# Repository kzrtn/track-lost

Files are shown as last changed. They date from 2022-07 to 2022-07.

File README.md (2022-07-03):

# TRACK LOST
F12 TKL type-C PCB for the Duck Orion. Designed in KiCad 6.0

track lost PCB front
track lost PCB back
track lost PCB traces

## Features
- [QMK](https://docs.qmk.fm/#/) and [VIAL](https://get.vial.today/) compatible
- Uses an RP2040 MCU with 32MB of external flash
- Uses WS2812C-2020 LEDs for smaller footprint and less power usage
- Has more underglow LEDs for better LED diffusion
- Indicators use SK6812mini-e LEDs instead
- Multi-layout
- BOOTRESET button if bootmagic isn't available
- ESD chip to prevent damage from electrostatic discharge
- Polyfuse to prevent overcurrent
- Gerber and files available for manufacturing and assembly with JLCPCB (In `track-lost/JLCPCB folder`)
- Curved traces

## Firmware
WIP

## Multi-Layout Support
- Supports both ANSI and ISO layouts
- Supports both 6.25u and 7u spacebar
- Supports split backspace
- Supports split right shift

Multilayout image

## Indicator LEDs
The typical LEDs on the original Duck Orion PCB are TX LEDs that you have to solder in. But for this PCB, SK6812mini-e reverse-mount ARGB LEDs were used instead.
- Reverse mount to keep all components on the same side of the PCB for cheaper assembly
- RGB and programmable
- NOTE: Because these are surface mounted onto the PCB, they'll likely leak light (I'll update this when I test it out). Could be fixed with light pipes or something else to isolate the rays from each other.

top left indicators
above arrow key indicators

## WIP
- Add photos of PCBs
- Add photos of PCB in case
- Add photo of original PCB LED difussion vs TRACK LOST PCB LED difussion
- Create and add firmware to repo

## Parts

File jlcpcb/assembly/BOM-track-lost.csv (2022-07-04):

Comment | Designator | Footprint | LCSC
D | D1,D10,D11,D12,D13,D14,D15,D16,D17,D18,D19,D2,D20,D21,D22,D23,D24,D25,D26,D27,D28,D29,D3,D30,D31,D32,D33,D34,D35,D36,D37,D38,D39,D4,D40,D41,D42,D43,D44,D45,D46,D47,D48,D49,D5,D50,D51,D52,D53,D54,D55,D56,D57,D58,D59,D6,D60,D61,D62,D63,D64,D65,D66,D67,D68,D69,D7,D70,D71,D72,D73,D74,D75,D76,D77,D78,D79,D8,D80,D81,D82,D83,D84,D85,D86,D87,D88,D89,D9,D90 | D_SOD-123 | C81598
BACKSPACE | S1 | STAB_MX_2u
? | SW33 | SW_MX_1u
? | SW82 | SW_MX_1u
? | SW76 | SW_MX_1u
? | SW8 | SW_MX_1u
? | SW83 | SW_MX_1u
? | SW2 | SW_MX_1u
? | SW28 | SW_MX_1u
? | SW42 | SW_MX_1u
? | SW36 | SW_MX_1u
? | SW95 | SW_MX_1.25u
? | SW97 | SW_MX_1.25u
? | SW84 | SW_MX_1.75u
? | SW90 | SW_MX_1u
? | SW51 | SW_MX_1u
? | SW87 | SW_MX_1.25u
? | SW80 | SW_MX_1u
? | SW27 | SW_MX_1u
? | SW9 | SW_MX_1u
? | SW100 | SW_MX_1.25u
? | SW67 | SW_MX_1u
? | SW71 | SW_MX_1u
? | SW40 | SW_MX_1u
? | SW52 | SW_MX_1u
? | SW15 | SW_MX_1u
? | SW46 | SW_MX_1u
? | SW49 | SW_MX_1u
? | SW68 | SW_MX_1u
? | SW65 | SW_MX_1u
? | SW101 | SW_MX_1u
? | SW43 | SW_MX_1u
? | SW79 | SW_MX_1u
? | SW61 | SW_MX_1u
? | SW38 | SW_MX_1u
? | SW34 | SW_MX_1u
? | SW5 | SW_MX_1u
? | SW30 | SW_MX_1u
? | SW57 | SW_MX_1u
? | SW53 | SW_MX_1u
? | SW21 | SW_MX_1u
RSHIFT | S5 | STAB_MX_2.75u
? | SW16 | SW_MX_1u
? | SW47 | SW_MX_1u
? | SW104 | SW_MX_1u
? | SW102 | SW_MX_1u
? | SW69 | SW_MX_1u
? | SW75 | SW_MX_1u
? | SW31 | SW_MX_1u
? | SW24 | SW_MX_1u
? | SW92 | SW_MX_1.5u
ANSI_ENTER | S3 | STAB_MX_2.25u
? | SW32 | SW_MX_1u
? | SW59 | SW_MX_1u
? | SW6 | SW_MX_1u
? | SW58 | SW_MX_1u
? | SW77 | SW_MX_1u
? | SW103 | SW_MX_1u
6.25U_SPACE | S6 | STAB_MX_6.25u
? | SW62 | SW_MX_1u
? | SW20 | SW_MX_1u
? | SW44 | SW_MX_1u
? | SW45 | SW_MX_1u
? | SW4 | SW_MX_1u
? | SW74 | SW_MX_1u
? | SW26 | SW_MX_1u
? | SW89 | SW_MX_1.25u
? | SW50 | SW_MX_1.5u
? | SW91 | SW_MX_1.25u
? | SW13 | SW_MX_1u
? | SW17 | SW_MX_1u
? | SW85 | SW_MX_1u
? | SW60 | SW_MX_1u
? | SW48 | SW_MX_1u
? | SW3 | SW_MX_1u
7U_SPACE | S7 | STAB_MX_7u
? | SW56 | SW_MX_1.75u
? | SW93 | SW_MX_1u
? | SW41 | SW_MX_1u
? | SW98 | SW_MX_1u
? | SW73 | SW_MX_1u
? | SW64 | SW_MX_1u
? | SW54 | SW_MX_1u
? | SW88 | SW_MX_1.5u
? | SW78 | SW_MX_1u
? | SW23 | SW_MX_1u
? | SW39 | SW_MX_1u
? | SW10 | SW_MX_1u
? | SW22 | SW_MX_1u
? | SW70 | SW_MX_1.25u
? | SW99 | SW_MX_1.25u
LSHIFT | S4 | STAB_MX_2.25u
? | SW96 | SW_MX_1.5u
? | SW7 | SW_MX_1u
? | SW25 | SW_MX_1u
? | SW37 | SW_MX_1.5u
? | SW35 | SW_MX_1u
? | SW86 | SW_MX_1u
? | SW12 | SW_MX_1u
? | SW55 | SW_MX_1.75u_stp
? | SW11 | SW_MX_1u
? | SW66 | SW_MX_1u
? | SW29 | SW_MX_1u
? | SW14 | SW_MX_1u
? | SW72 | SW_MX_1u
ISO_ENTER | S2 | STAB_MX_ISO_FLIPPED
? | SW18 | SW_MX_1u
? | SW94 | SW_MX_1u
? | SW63 | SW_MX_1u
? | SW19 | SW_MX_1u
? | SW81 | SW_MX_1u
1u | C17 | C_0402_1005Metric
SK6812MINI-E | LED7 | LED_WS2812_2020
1k | R7 | R_0402_1005Metric
100n | C31 | C_0402_1005Metric
SK6812MINI-E | LED6 | LED_WS2812_2020
SK6812MINI-E | LED27 | LED_WS2812_2020
RP2040 | U4 | RP2040-QFN-56
5.1k | R1 | R_0402_1005Metric
SK6812MINI-E | LED23 | LED_WS2812_2020
100n | C22 | C_0402_1005Metric
100n | C24 | C_0402_1005Metric
SK6812MINI-E | LED2 | LED_6028R
W25Q32JVSS | U3 | SOIC-8_5.23x5.23mm_P1.27mm
SK6812MINI-E | LED16 | LED_WS2812_2020
SK6812MINI-E | LED31 | LED_WS2812_2020
100n | C7 | C_0402_1005Metric
100n | C26 | C_0402_1005Metric
100n | C13 | C_0402_1005Metric
100n | C35 | C_0402_1005Metric
SK6812MINI-E | LED13 | LED_WS2812_2020
Crystal_GND24_Small | Y1 | Crystal_SMD_3225-4Pin_3.2x2.5mm
100n | C10 | C_0402_1005Metric
SK6812MINI-E | LED32 | LED_WS2812_2020
74AHCT1G125 | U5 | SOT-23-5
1uF | C3 | C_0402_1005Metric
SK6812MINI-E | LED1 | LED_6028R
1u | C8 | C_0402_1005Metric
100n | C49 | C_0402_1005Metric
100n | C34 | C_0402_1005Metric
SK6812MINI-E | LED10 | LED_WS2812_2020
100n | C44 | C_0402_1005Metric
100n | C25 | C_0402_1005Metric
100n | C1 | C_0402_1005Metric
SK6812MINI-E | LED24 | LED_WS2812_2020
100n | C6 | C_0402_1005Metric
100n | C46 | C_0402_1005Metric
100n | C23 | C_0402_1005Metric
1uF | C2 | C_0402_1005Metric
SK6812MINI-E | LED26 | LED_WS2812_2020
SK6812MINI-E | LED28 | LED_WS2812_2020
100n | C48 | C_0402_1005Metric
100n | C30 | C_0402_1005Metric
100n | C20 | C_0402_1005Metric
SW_Push | SW1 | SW_SPST_SKQG_WithStem
SK6812MINI-E | LED20 | LED_WS2812_2020
SK6812MINI-E | LED17 | LED_6028R
27 | R6 | R_0402_1005Metric
SK6812MINI-E | LED4 | LED_6028R
100n | C27 | C_0402_1005Metric
100n | C19 | C_0402_1005Metric
1k | R4 | R_0402_1005Metric
SK6812MINI-E | LED29 | LED_WS2812_2020
100n | C12 | C_0402_1005Metric
500mA | F1 | Fuse_0402_1005Metric
SK6812MINI-E | LED19 | LED_6028R
100n | C36 | C_0402_1005Metric
100n | C14 | C_0402_1005Metric
SK6812MINI-E | LED30 | LED_WS2812_2020
27 | R5 | R_0402_1005Metric
SK6812MINI-E | LED9 | LED_WS2812_2020
SK6812MINI-E | LED25 | LED_WS2812_2020
SK6812MINI-E | LED8 | LED_WS2812_2020
20pF | C4 | C_0402_1005Metric
100n | C33 | C_0402_1005Metric
5.1k | R3 | R_0402_1005Metric
100n | C47 | C_0402_1005Metric
100n | C32 | C_0402_1005Metric
SK6812MINI-E | LED11 | LED_WS2812_2020
100n | C21 | C_0402_1005Metric
100n | C28 | C_0402_1005Metric
SK6812MINI-E | LED22 | LED_WS2812_2020
100n | C42 | C_0402_1005Metric
100n | C38 | C_0402_1005Metric
SRV05-4 | U2 | SOT-23-6-routable
20pF | C5 | C_0402_1005Metric
SK6812MINI-E | LED21 | LED_WS2812_2020
SK6812MINI-E | LED5 | LED_6028R
SK6812MINI-E | LED18 | LED_6028R
SK6812MINI-E | LED12 | LED_WS2812_2020
XC6206PxxxMR | U1 | SOT-23
100n | C39 | C_0402_1005Metric
100n | C11 | C_0402_1005Metric
100n | C9 | C_0402_1005Metric
SK6812MINI-E | LED15 | LED_WS2812_2020
100n | C29 | C_0402_1005Metric
100n | C41 | C_0402_1005Metric
100n | C45 | C_0402_1005Metric
100n | C37 | C_0402_1005Metric
100n | C43 | C_0402_1005Metric
SK6812MINI-E | LED14 | LED_WS2812_2020
100n | C40 | C_0402_1005Metric
100n | C18 | C_0402_1005Metric
100n | C15 | C_0402_1005Metric
DNF | R2 | R_0402_1005Metric
100n | C16 | C_0402_1005Metric
USB_C_Receptacle_USB2.0 | J1 | USB_C_Receptacle_HRO_TYPE-C-31-M-12
SK6812MINI-E | LED3 | LED_6028R

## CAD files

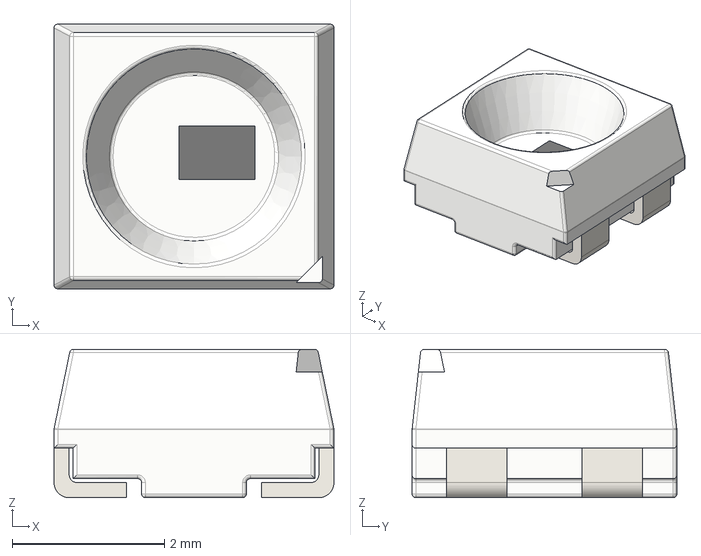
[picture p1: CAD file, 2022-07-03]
marbastlib/3d/LED_WS2812B-MINI.step
3.68 x 3.48 x 1.95 mm

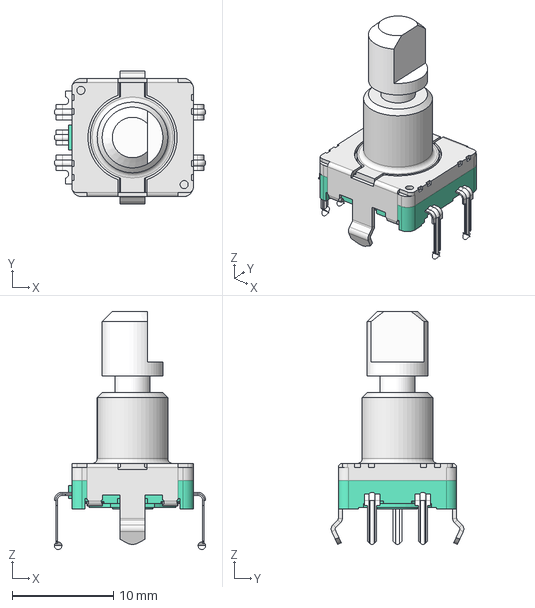
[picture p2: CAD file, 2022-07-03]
marbastlib/3d/ROT_EC11N.step
14.9 x 13.1 x 23.5 mm

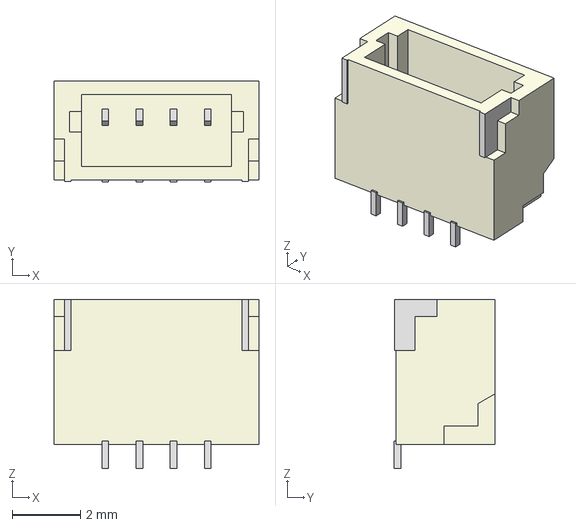
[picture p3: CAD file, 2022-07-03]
marbastlib/3d/CON_SM04B-SRSS-TB.step
6.00 x 2.96 x 4.95 mm

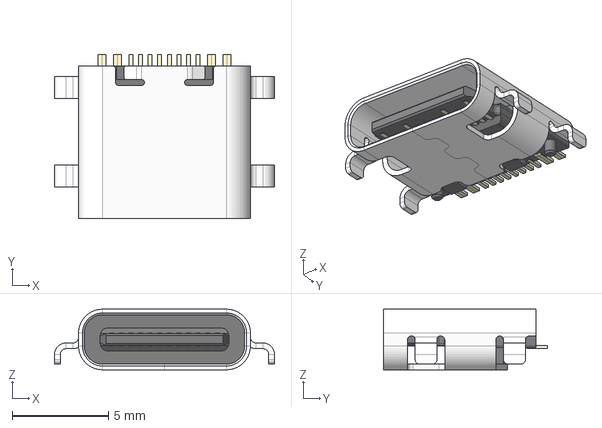
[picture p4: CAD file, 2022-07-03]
marbastlib/3d/CON_TYPE-C-31-M-14.step
11.5 x 8.56 x 3.16 mm
Shroud
Plastic Body & Connector

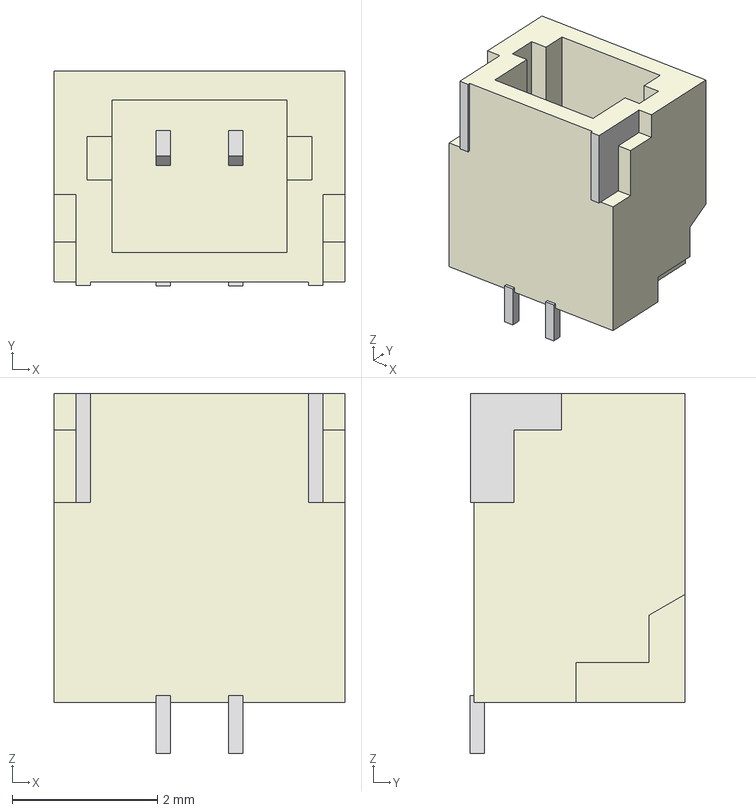
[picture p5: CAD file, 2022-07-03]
marbastlib/3d/CON_SM02B-SRSS-TB.step
4.00 x 2.96 x 4.95 mm

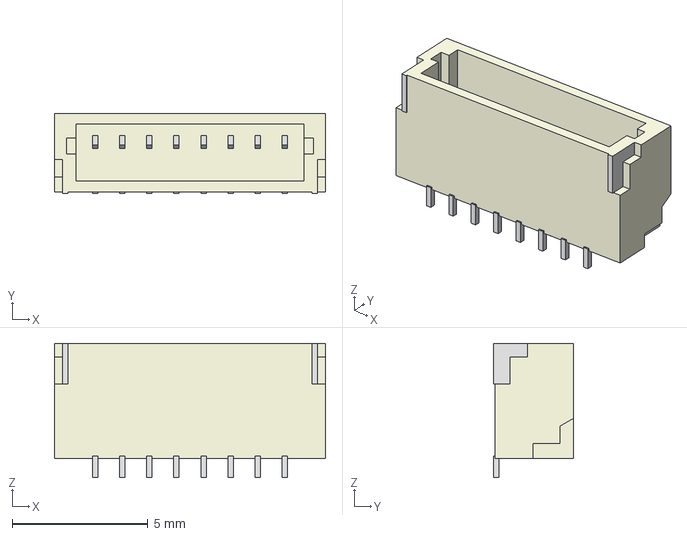
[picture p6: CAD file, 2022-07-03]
marbastlib/3d/CON_SM08B-SRSS-TB.step
10.0 x 2.96 x 4.95 mm

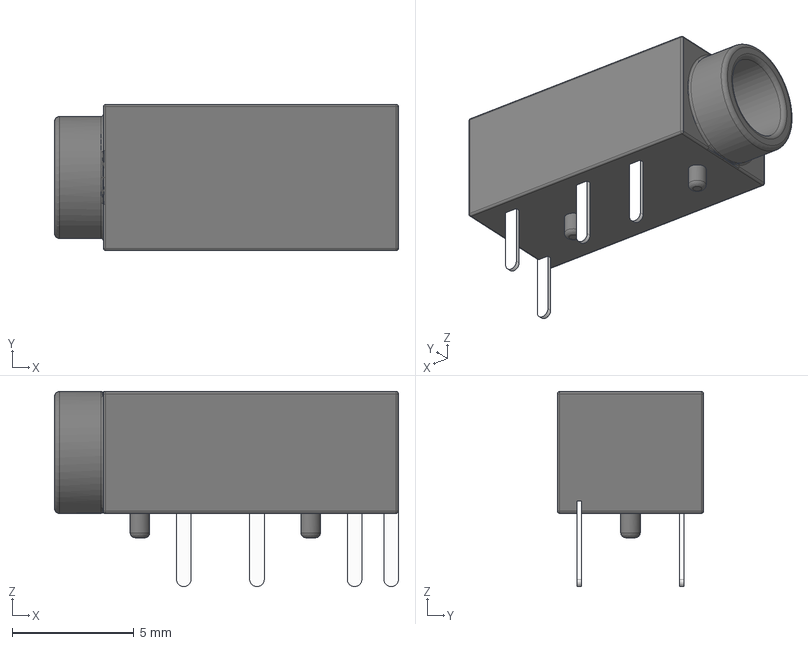
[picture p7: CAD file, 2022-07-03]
marbastlib/3d/CON_MJ-4PP-9.step
14.1 x 6.00 x 8.00 mm

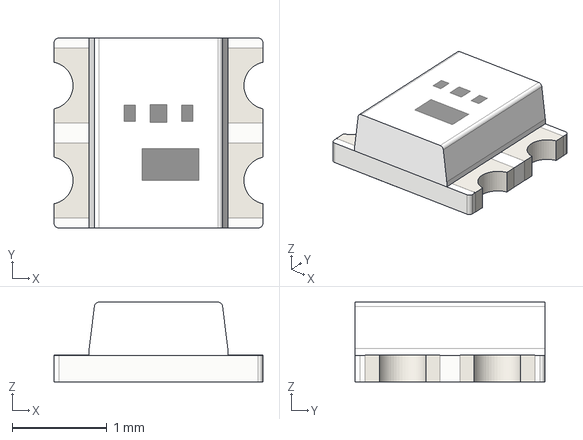
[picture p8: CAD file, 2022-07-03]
marbastlib/3d/LED_WS2812_2020.step
2.20 x 2.00 x 0.842 mm

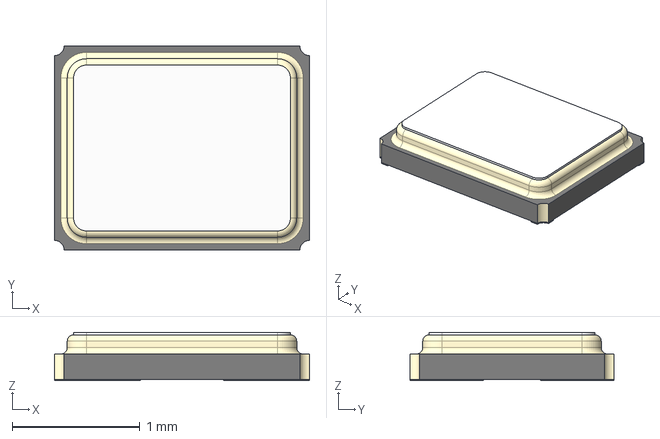
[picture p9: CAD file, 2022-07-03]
marbastlib/3d/Crystal_FA-128.step
2.00 x 1.60 x 0.38 mm

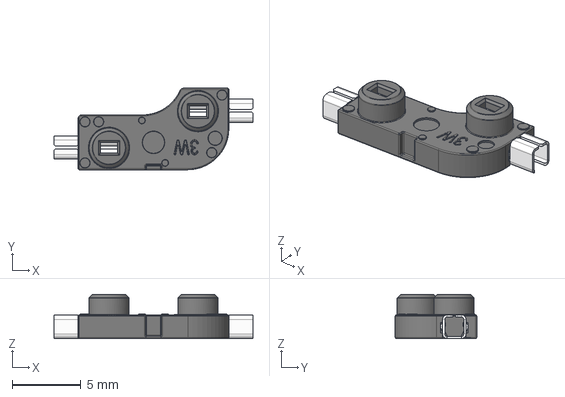
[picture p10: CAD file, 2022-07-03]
marbastlib/3d/HS_Kailh_MX.step
14.5 x 5.95 x 3.22 mm

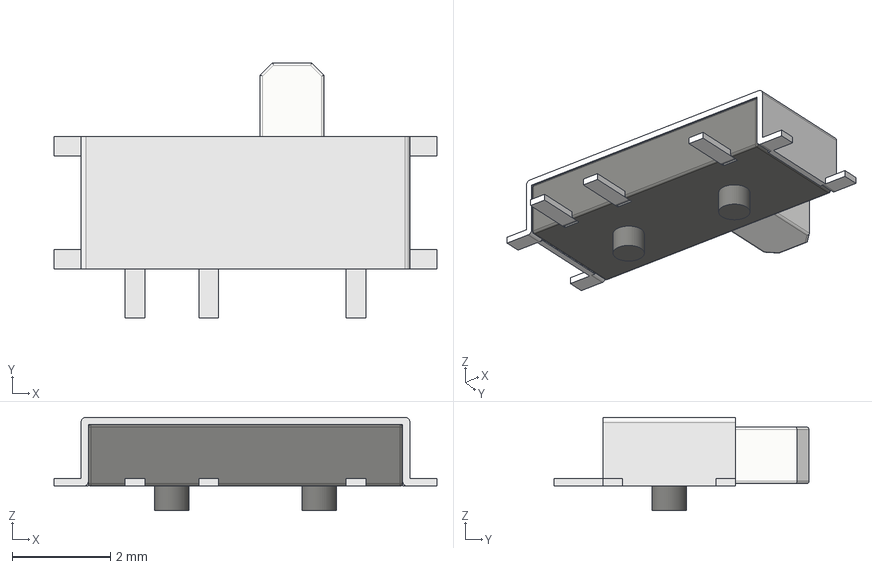
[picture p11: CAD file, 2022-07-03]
marbastlib/3d/MSK12C02.step
7.80 x 5.20 x 1.90 mm

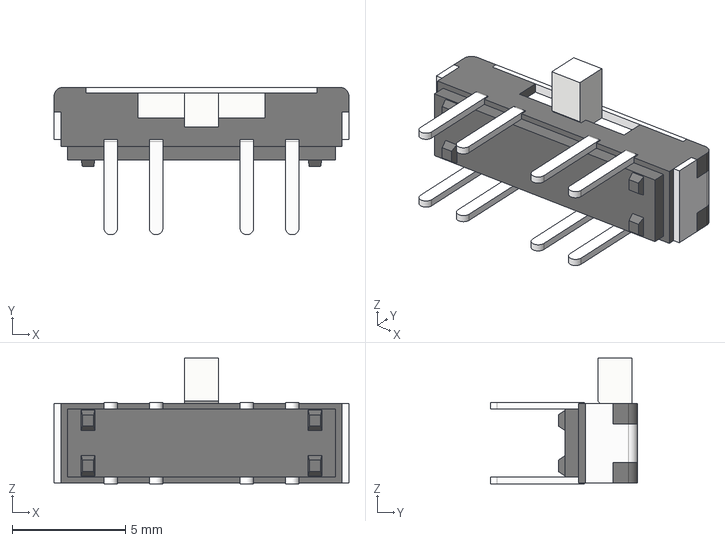
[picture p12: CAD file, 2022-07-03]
marbastlib/3d/SW_SSSS223900.step
13.0 x 6.50 x 5.55 mm

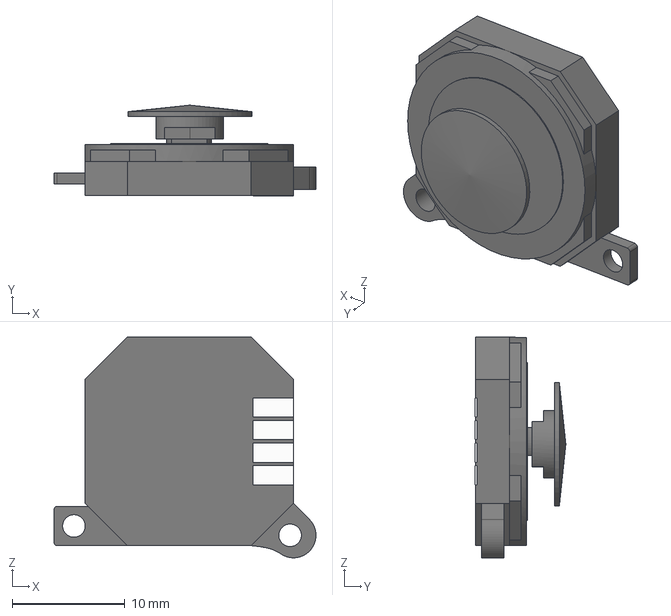
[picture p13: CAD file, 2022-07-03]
marbastlib/3d/joystick_psp1000.step
23.2 x 8.05 x 19.6 mm

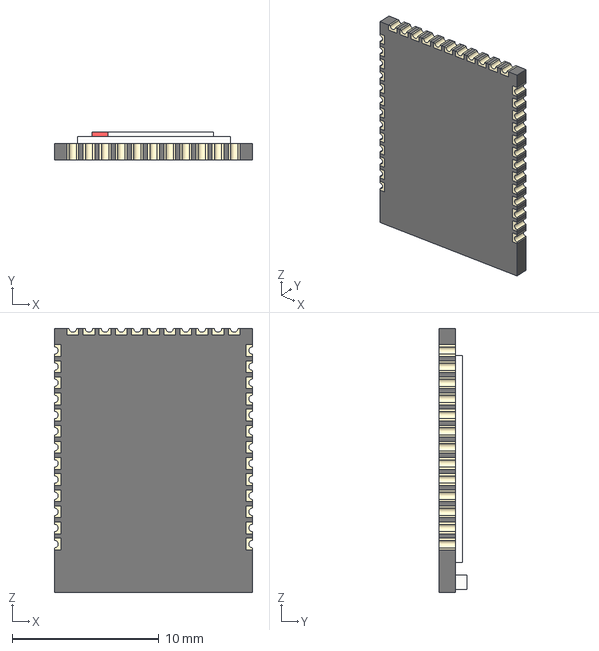
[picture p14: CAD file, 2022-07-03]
marbastlib/3d/holyiot_18010_nRF52840.step
13.5 x 1.92 x 18.0 mm

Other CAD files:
marbastlib/3d/CON_SM06B-SRSS-TB.step
marbastlib/3d/Switch_ESP3020.step
marbastlib/3d/CON_SM05B-SRSS-TB.step
marbastlib/3d/CON_TYPE-C-31-M-12.step
marbastlib/3d/CON_SM07B-SRSS-TB.step
marbastlib/3d/CON_SM13B-SRSS-TB.step
marbastlib/3d/HS_Kailh_Choc.step
marbastlib/3d/LED_SK6812MINI-E.step
marbastlib/3d/ROT_EC11E.step
marbastlib/3d/SW_SKHLLC.step
marbastlib/3d/SW_SSSS213100.step
marbastlib/3d/Switch_MSK12C02.step
marbastlib/3d/Switch_SKQG.step

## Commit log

2022-07-03 Generated updated gerber files and deleted unnecessary files
    [BOM-track-lost.csv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]
2022-07-03 Updated symbol and footprint library paths
    [BOM-orion-PCB.csv, LEDs.kicad_sch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]
2022-07-03 gitignore are you working
    [LEDs.kicad_sch]
2022-07-04 Changed capacitor values for crystal
    I ACCIDENTALLY DIVIDED BY 2 INSTEAD OF MULTIPLY BY 2
    [BOM-track-lost.csv, LEDs.kicad_sch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]
